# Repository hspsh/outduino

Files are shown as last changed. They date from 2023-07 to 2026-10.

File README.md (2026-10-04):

# Outduino

This is a board we did back in 2023, for our ninja warrior timer.

The core requirements of the projects were - create a device that would:
* drive 2 HDMI outputs (for timer output)
* Register inputs from large switches, on very long cables
* Flash LED outputs.

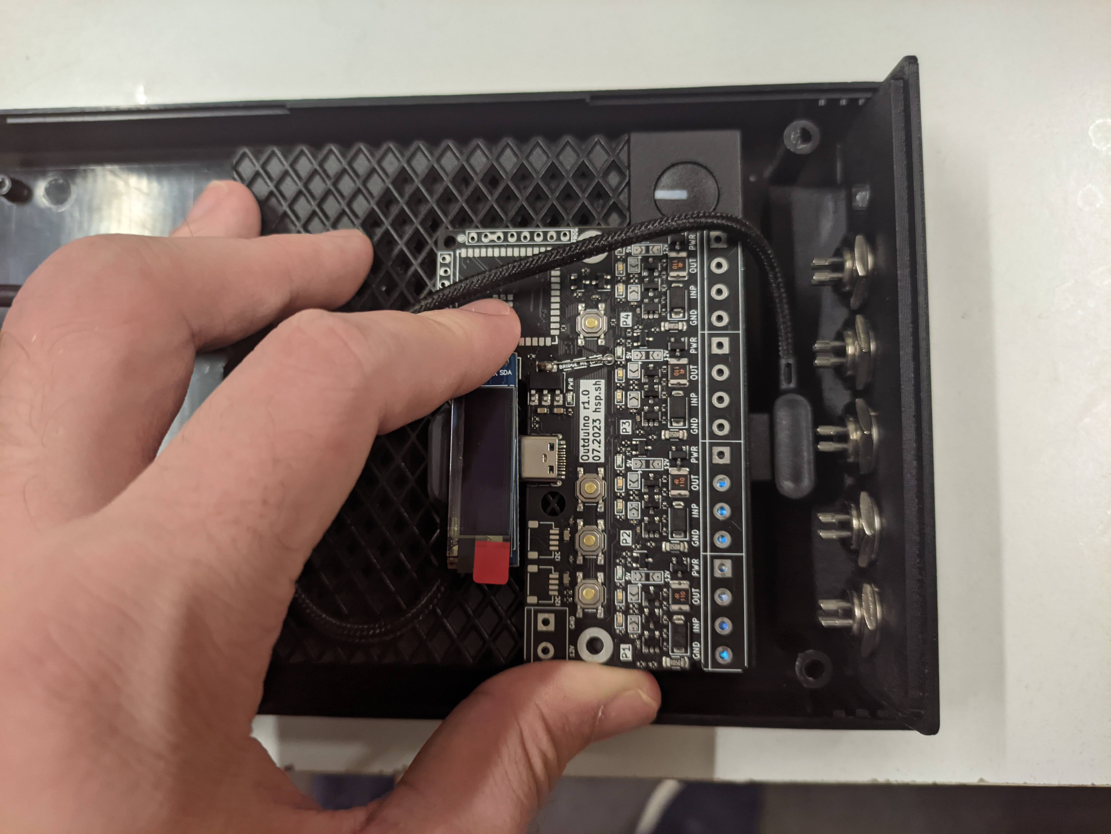
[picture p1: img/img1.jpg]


At first we considered adding some I/O buffer circuitry to raspberry pi, but we decided that a cheaper and more reliable version (if not the more interesting one!) would consist of a Dell Wyse 3040 hidden inside a case, and having a standalone, overengineered, ESP-based IO module drive and read Inputs/Outputs. This is how Outduino was made.

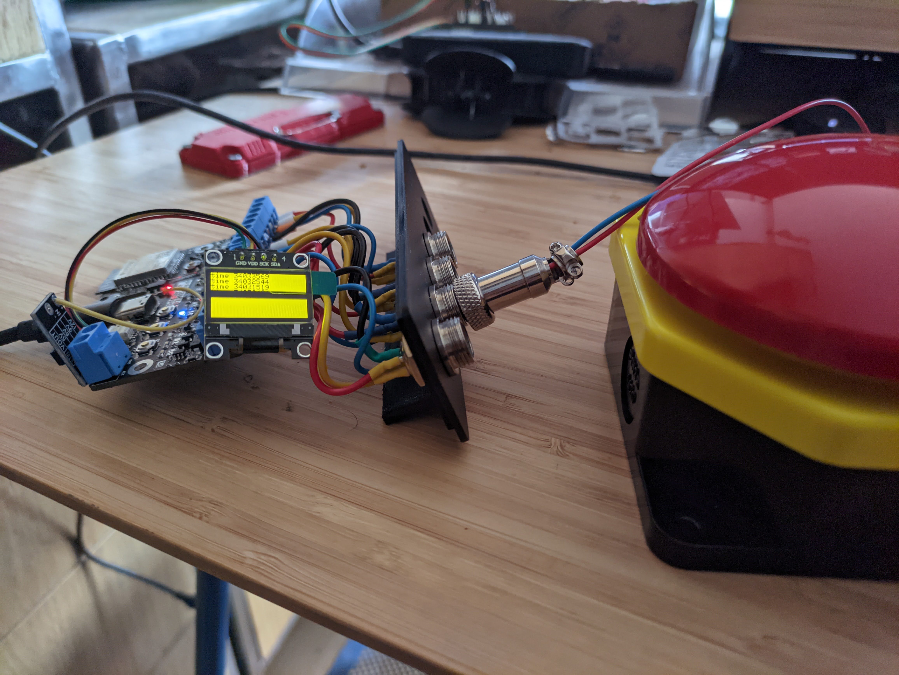
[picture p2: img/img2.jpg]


## I/O block

The device contains 4 overengineered blocks of I/O. These should be able to handle very long cables, as long as the peripherals are not going across different electrical phases. This installation was used outdoor, so this is fine.

As I'm writing this, the year is 2026, I'm 3 years wiser, and I'd probably go full galvanic isolation for both input (optocoupler) and output (something like B0505S isolated converter).



## ESP32

The board connects via USB, and uses very simple API via serial port, to control I/O from software running on host machine.

This part worked well.

In future, the board could've been made to work wirelessly. There's even a footprint for CC1101 sub-ghz wireless IC connection. These functionalities were never added to the firmware.



## Thank yous

Thank you LiquidLemon, not7cd, for inviting me to the project.

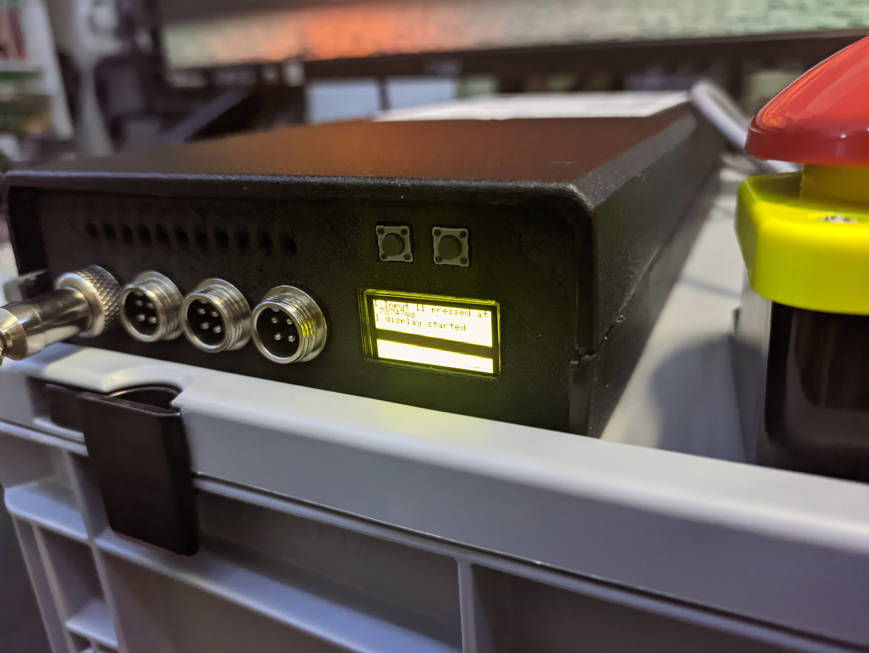
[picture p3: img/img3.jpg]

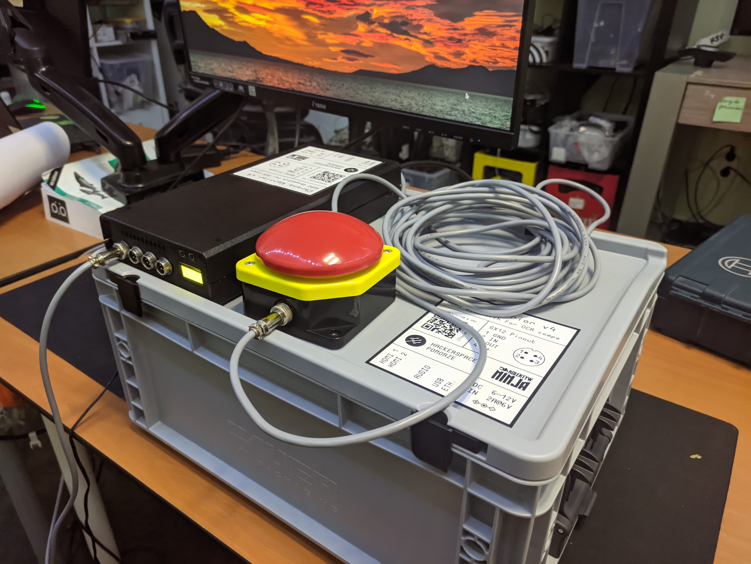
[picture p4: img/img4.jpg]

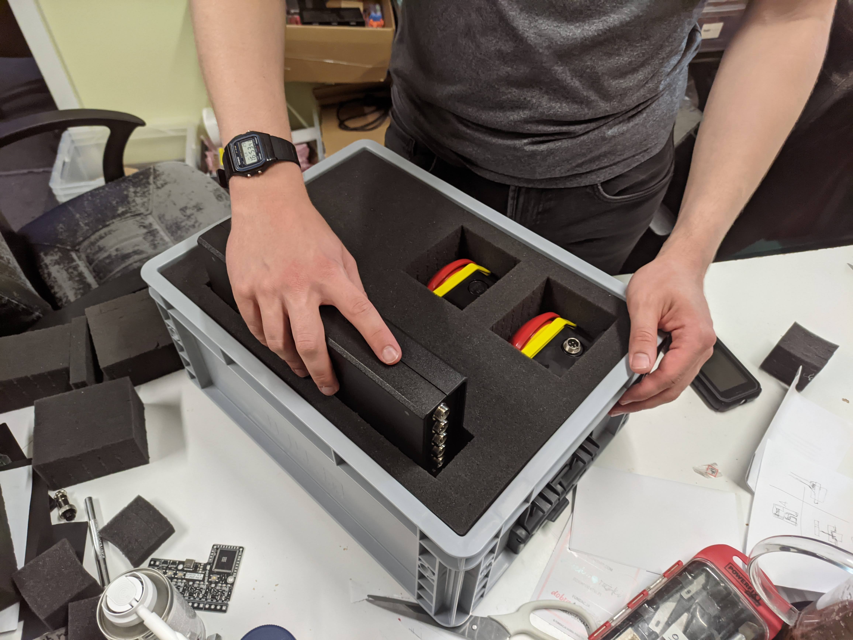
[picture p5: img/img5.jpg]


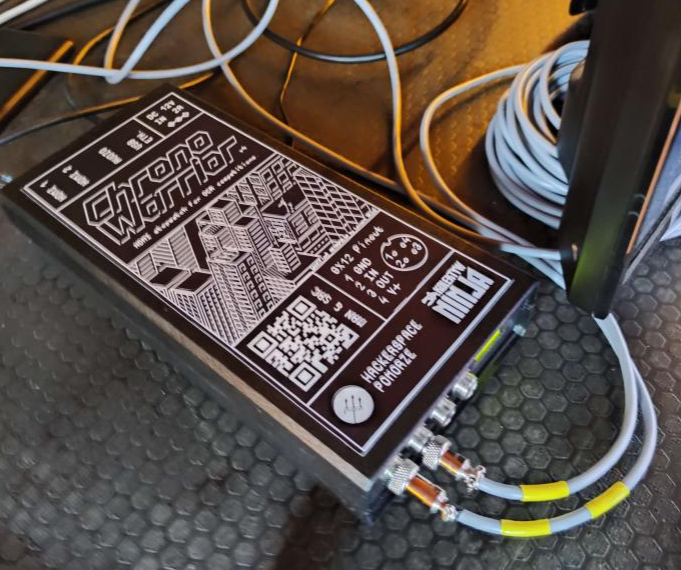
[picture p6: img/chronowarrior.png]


[Project website](https://hsp.sh/chronowarrior)

## License

Copyright 2023 Jakub "cr1tbit" Sadowski.

* **Hardware** (KiCad sources, production files and this documentation) is
  licensed under the [CERN-OHL-P v2](LICENSE) (permissive). You may
  redistribute and modify it and make products using it under the terms of
  that licence.
* **Firmware** in [outduino-fw/](outduino-fw/) is licensed under the
  [MIT License](outduino-fw/LICENSE).

This source is distributed WITHOUT ANY EXPRESS OR IMPLIED WARRANTY, INCLUDING
OF MERCHANTABILITY, SATISFACTORY QUALITY AND FITNESS FOR A PARTICULAR PURPOSE.
Please see the CERN-OHL-P v2 for applicable conditions.

Symbols and footprints from the KiCad and Espressif libraries embedded in the
design files remain under their respective licences.

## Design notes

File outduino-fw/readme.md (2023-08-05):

esptool.py --chip ESP32-S3 merge_bin -o merged-flash.bin --flash_size=keep 0x00000 bootloader.bin 0x8000 partitions.bin 0xe000 ~/.platformio/packages/framework-arduinoespressif32/tools/partitions/boot_app0.bin 0x10000 firmware.bin

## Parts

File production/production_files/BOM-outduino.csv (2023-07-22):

Comment | Designator | Footprint | LCSC
1k | R64,R65,R66,R67 | R_0402_1005Metric | C11702
AO3401A | Q12,Q3,Q6,Q9 | SOT-23 | C15127
100n | C1,C10,C11,C12,C13,C14,C15,C5,C6,C7,C8,C9 | C_0402_1005Metric | C1525
USB_C_Receptacle_USB2.0 | J1 | USB_C_Receptacle_HRO_TYPE-C-31-M-12 | C165948
1812_2A | F1,F2,F3,F4 | Fuse_1812_4532Metric | C20999
LED_RED | D1,D12,D17,D4,D7 | LED_0603_1608Metric | C2286
330/0.1% | R36,R37,R46,R48 | R_0402_1005Metric | C25104
5.1k | R3 | R_0402_1005Metric | C25117
100k | R29,R30,R31 | R_0402_1005Metric | C25741
10k | R1,R10,R11,R12,R13,R14,R19,R21,R22,R23,R24,R25,R26,R27,R28,R33,R39,R40,R41,R42,R43,R45,R49,R51,R52,R53,R54,R55,R57,R58,R60,R61,R63,R68,R69,R7,R70,R71,R72,R73,R74,R75,R8,R9 | R_0402_1005Metric | C25744
3k | R15,R16,R18,R32,R35,R38,R4,R44,R47,R5,R50,R56,R59,R62 | R_0402_1005Metric | C25890
5.1k | R2 | R_0402_1005Metric | C25905
D_TVS | D11,D16,D21,D3 | D_SMA | C3019524
RST | SW1,SW3,SW4,SW5 | SW_SPST_TL3342 | C318884
AZ1117-3.3 | U2 | SOT-223-3_TabPin2 | C6186
LED_BLUE | D14,D19,D6,D9 | LED_0603_1608Metric | C72041
LED_GREEN | D13,D18,D5,D8 | LED_0603_1608Metric | C72043
LMV321 | U4,U5,U6,U7 | SOT-23-5 | C7972
MMBT2222A | Q1,Q10,Q11,Q13,Q14,Q15,Q16,Q17,Q18,Q2,Q4,Q5,Q7,Q8 | SOT-23 | C8512
50mR/1206 | R17,R20,R34,R6 | R_1206_3216Metric_Pad1.30x1.75mm_HandSolder | C912768
10u | C16,C17,C2,C3,C4 | C_0603_1608Metric | C96446

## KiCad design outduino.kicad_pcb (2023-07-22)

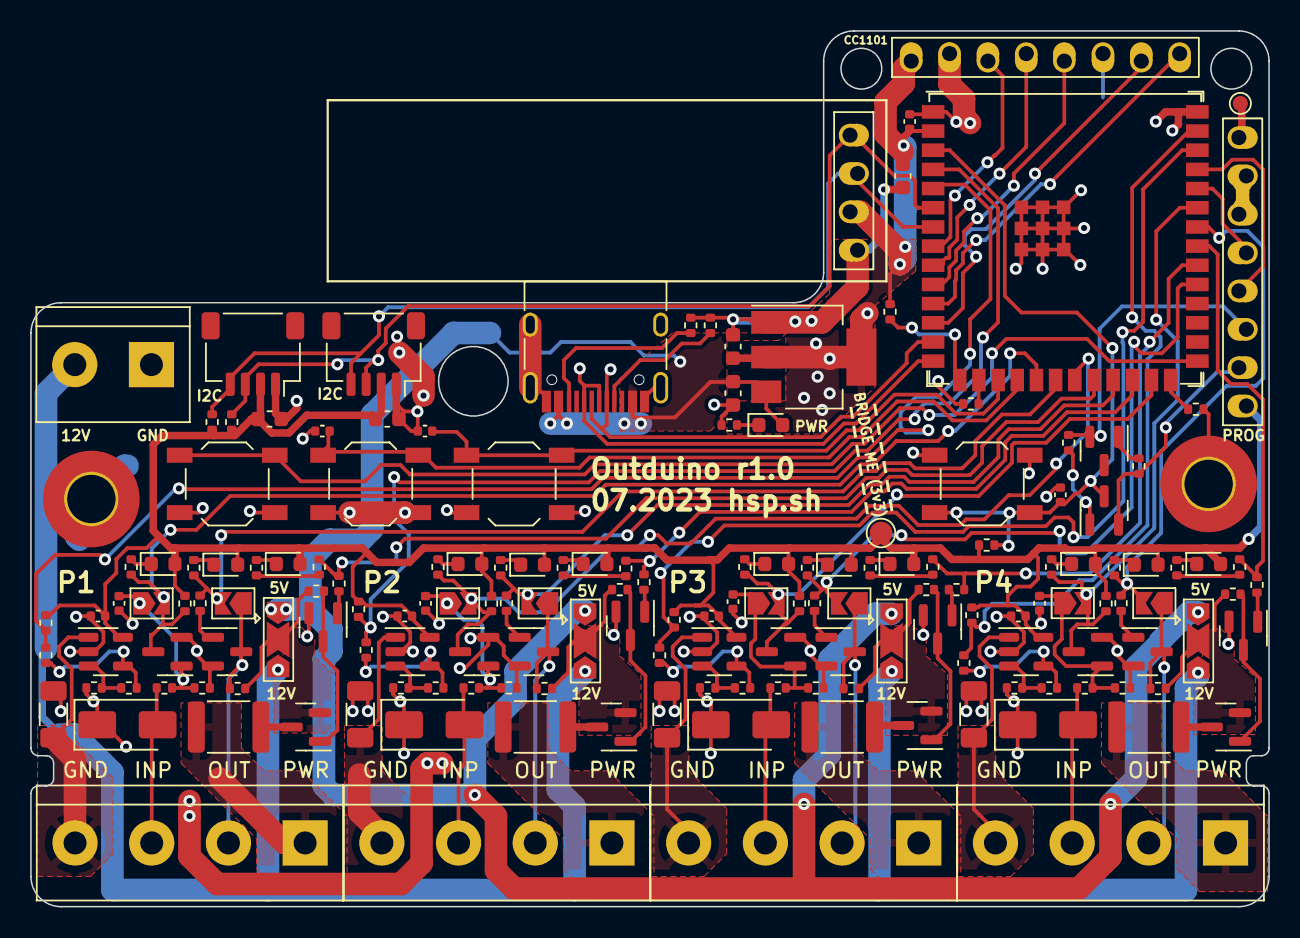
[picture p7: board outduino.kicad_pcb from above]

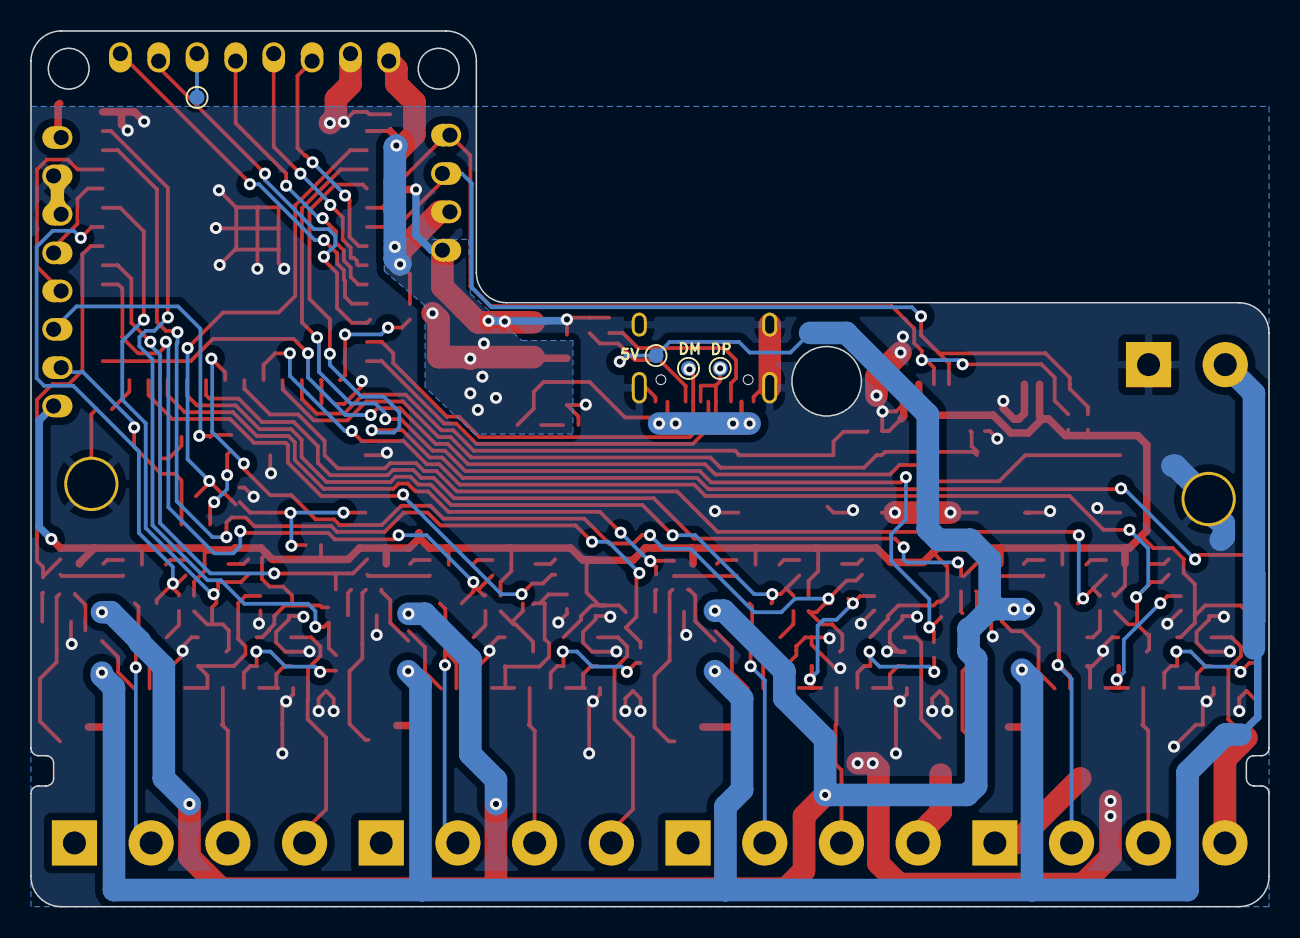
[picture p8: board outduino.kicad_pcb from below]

Board: 2 copper layers, 82.0 x 58.0 mm, 172 parts (4 on the bottom side), 111 nets.

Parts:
C1, C5, C6, C7, C8, C9, C10, C11, C12, C13, C14, C15: 100n; C_0402_1005Metric
C2, C3, C4, C16, C17: 10u; C_0603_1608Metric
D1, D4, D7, D12, D17: LED_RED; LED_0603_1608Metric
D3, D11, D16, D21: D_TVS; D_SMA
D5, D8, D13, D18: LED_GREEN; LED_0603_1608Metric
D6, D9, D14, D19: LED_BLUE; LED_0603_1608Metric
F1, F2, F3, F4: 1812_2A; Fuse_1812_4532Metric
H1, H3: SCR; MountingHole_3.2mm_M3_Pad_TopOnly
J1: USB_C_Receptacle_USB2.0; USB_C_Receptacle_HRO_TYPE-C-31-M-12
J2: Lichtenprog_conn; Lichtenprog
J3: Conn_01x02; TerminalBlock_bornier-2_P5.08mm
J4, J6: QWIIC; JST_SH_SM04B-SRSS-TB_1x04-1MP_P1.00mm_Horizontal
J5, J7, J8, J9: Conn_01x04; TerminalBlock_bornier-4_P5.08mm
J10: CC1101_CONN; 8pin_skewed
JP3, JP4, JP5, JP6: VSEL; SolderJumper-3_P2.0mm_Open_TrianglePad1.0x1.5mm
JP7, JP8, JP9, JP10: OUT_BYP; SolderJumper-2_P1.3mm_Open_TrianglePad1.0x1.5mm
JP11, JP12, JP13, JP14: IN_BYP; SolderJumper-2_P1.3mm_Open_TrianglePad1.0x1.5mm
Q1, Q2: MMBT2222A; SOT-23
Q3, Q6, Q9, Q12: AO3401A; SOT-23
Q4, Q5, Q7, Q8, Q10, Q11, Q13, Q14, Q15, Q16, Q17, Q18: BC847; SOT-23
R1, R7, R8, R9, R10, R11, R12, R13, R14, R19, R21, R22, R23, R24, R25, R26, R27, R28, R33, R39, R40, R41, R42, R43, R45, R49, R51, R52, R53, R54, R55, R57, R58, R60, R61, R63, R68, R69, R70, R71, R72, R73, R74, R75: 10k; R_0402_1005Metric
R2, R3: 5.1k; R_0402_1005Metric
R4, R5, R15, R16, R18, R32, R35, R38, R44, R47, R50, R56, R59, R62: 3k; R_0402_1005Metric
R6, R17, R20, R34: 50mR/1206; R_1206_3216Metric_Pad1.30x1.75mm_HandSolder
R29, R30, R31: 100k; R_0402_1005Metric
R36, R37, R46, R48: 330/0.1%; R_0402_1005Metric
R64, R65, R66, R67: 1k; R_0402_1005Metric
SW1: RST; SW_SPST_TL3342
SW3: B1/BOOT; SW_SPST_TL3342
SW4, SW5: B2; SW_SPST_TL3342
TP1, TP2, TP3, TP4, TP5: IOPAD; TestPoint_Pad_D1.0mm
TP6: IOPAD; TestPoint_Pad_D1.5mm
U1: OLED_4Pin
U2: AZ1117-3.3; SOT-223-3_TabPin2
U3: ESP32-S3-WROOM-2; ESP32-S3-WROOM-1U
U4, U5, U6, U7: LMV321; SOT-23-5

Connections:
+3.3V: C1.1, C2.1, C4.1, C10.1, C13.1, C14.1, C15.1, C16.1, C17.1, D4.2 (A), D5.2 (A), D6.2 (A), D7.2 (A), D8.2 (A), D9.2 (A), D12.2 (A), D13.2 (A), D14.2 (A), D17.2 (A), D18.2 (A), D19.2 (A), J2.1 (VDD), J4.2, J6.2, J10.1, R4.2, R5.2, R16.2, R25.2, R30.2, R35.2, R47.2, R59.2, R68.1, R69.1, R70.1, R71.1, TP6.1, U1.2 (VCC), U2.2 (VO), U3.2 (3V3), U4.5 (V+), U5.5 (V+), U6.5 (V+), U7.5 (V+)
+12V: J3.2, JP3.3 (B), JP4.3 (B), JP5.3 (B), JP6.3 (B)
/CC1101_CSn: J10.8, U3.11 (GPIO18/U1RXD/ADC2_CH7/CLK_OUT3)
/CC1101_GDO0: J10.7, U3.12 (GPIO8/TOUCH8/ADC1_CH7/SUBSPICS1)
/CC1101_GDO2: J10.6, TP5.1
/CC1101_SCLK: J10.4, U3.9 (GPIO16/U0CTS/ADC2_CH5/XTAL_32K_NH5)
/CC1101_SI: J10.3, U3.8 (GPIO15/U0RTS/ADC2_CH4/XTAL_32K_P)
/CC1101_SO: J10.5, U3.10 (GPIO17/U1TXD/ADC2_CH6)
/CURR1: R64.1, R68.2, U3.5 (GPIO5/TOUCH5/ADC1_CH4)
/CURR2: R65.1, R69.2, U3.4 (GPIO4/TOUCH4/ADC1_CH3)
/CURR3: R66.1, R70.2, U3.38 (GPIO2/TOUCH2/ADC1_CH1)
/CURR4: R67.1, R71.2, U3.39 (GPIO1/TOUCH1/ADC1_CH0)
/DTR: J2.3 (DTR), Q2.2 (E), R7.1
/ESP_B2: C11.1, SW4.2, U3.17 (GPIO9/TOUCH9/ADC1_CH8/FSPIHD/SUBSPIHD)
/ESP_B3: C12.1, SW5.2, U3.18 (GPIO10/TOUCH10/ADC1_CH9/FSPICS0/FSPIIO4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)
/ESP_BOOT_B1: SW3.2, U3.27 (GPIO0/BOOT)
/ESP_EN: C8.1, Q1.3 (C), R25.1, SW1.2, U3.3 (EN)
/IN1: JP11.2 (B), Q5.3 (C), R16.1, R23.1, U3.19 (GPIO11/TOUCH11/ADC2_CH0/FSPID/FSPIIO5/S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)
/IN2: JP12.2 (B), Q8.3 (C), R27.1, R35.1, U3.21 (GPIO13/TOUCH13/ADC2_CH2/FSPIQ/FSPIIO7/S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)
/IN3: JP13.2 (B), Q11.3 (C), R42.1, R47.1, U3.25 (GPIO48/SPICLK_N/SUBSPICLK_N_DIFF)
/IN4: JP14.2 (B), Q14.3 (C), R54.1, R59.1, U3.35 (MTMS/GPIO42)
/IO_block1/GND_BANK: J5.4, R6.1, U4.1 (+)
/IO_block1/INP_BANK: D3.2 (A2), J5.3, R18.1
/IO_block1/OUT_BANK: J5.2, JP7.1 (A), Q4.3 (C), R15.1
/IO_block1/PWR: JP3.2 (C), Q3.2 (S), R14.2, R15.2
/IO_block1/PWR_BANK: F1.2, J5.1
/IO_block2/GND_BANK: J7.4, R17.1, U5.1 (+)
/IO_block2/INP_BANK: D11.2 (A2), J7.3, R38.1
/IO_block2/OUT_BANK: J7.2, JP8.1 (A), Q7.3 (C), R32.1
/IO_block2/PWR: JP4.2 (C), Q6.2 (S), R32.2, R33.2
/IO_block2/PWR_BANK: F2.2, J7.1
/IO_block3/GND_BANK: J8.4, R20.1, U6.1 (+)
/IO_block3/INP_BANK: D16.2 (A2), J8.3, R50.1
/IO_block3/OUT_BANK: J8.2, JP9.1 (A), Q10.3 (C), R44.1
/IO_block3/PWR: JP5.2 (C), Q9.2 (S), R44.2, R45.2
/IO_block3/PWR_BANK: F3.2, J8.1
/IO_block4/GND_BANK: J9.4, R34.1, U7.1 (+)
/IO_block4/INP_BANK: D21.2 (A2), J9.3, R62.1
/IO_block4/OUT_BANK: J9.2, JP10.1 (A), Q13.3 (C), R56.1
/IO_block4/PWR: JP6.2 (C), Q12.2 (S), R56.2, R57.2
/IO_block4/PWR_BANK: F4.2, J9.1
/OUT1: JP7.2 (B), R9.2, R22.1, U3.20 (GPIO12/TOUCH12/ADC2_CH1/FSPICLK/FSPIIO6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)
/OUT2: JP8.2 (B), R10.2, R26.1, U3.23 (GPIO21)
/OUT3: JP9.2 (B), R11.2, R41.1, U3.31 (GPIO38/FSPIWP/SUBSPIWP)
/OUT4: JP10.2 (B), R12.2, R53.1, U3.34 (MTDI/GPIO41/CLK_OUT1)
/PWR1: R24.1, R72.2, U3.22 (GPIO14/TOUCH14/ADC2_CH3/FSPIWP/FSPIDQS/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)
/PWR2: R28.1, R73.2, U3.24 (GPIO47/SPICLK_P/SUBSPICLK_P_DIFF)
/PWR3: R43.1, R74.2, U3.32 (MTCK/GPIO39/CLK_OUT3/SUBSPICS1)
/PWR4: R55.1, R75.2, U3.33 (MTDO/GPIO40/CLK_OUT2)
/RTS: J2.2 (RTS), Q1.2 (E), R8.1
/SCL: J4.4, J6.4, R4.1, U1.3 (SCL), U3.7 (GPIO7/TOUCH7/ADC1_CH6)
/SDA: J4.3, J6.3, R5.1, U1.4 (SDA), U3.6 (GPIO6/TOUCH6/ADC1_CH5)
/TARG_RX: J2.5 (PROG_TX), U3.36 (U0RXD/GPIO44/CLK_OUT2)
/TARG_TX: J2.4 (PROG_RX), U3.37 (U0TXD/GPIO43/CLK_OUT1)
/USBDM: J1.A7 (D-), J1.B7 (D-), TP3.1, U3.13 (GPIO19/U1RTS/ADC2_CH8/CLK_OUT2/USB_D-)
/USBDP: J1.A6 (D+), J1.B6 (D+), TP2.1, U3.14 (GPIO20/U1CTS/ADC2_CH9/CLK_OUT1/USB_D+)
GND: C1.2, C2.2, C3.2, C4.2, C5.2, C6.2, C7.2, C8.2, C9.2, C10.2, C11.2, C12.2, C13.2, C14.2, C15.2, C16.2, C17.2, D3.1 (A1), D11.1 (A1), D16.1 (A1), D21.1 (A1), H1.1, H3.1, J1.A1 (GND), J1.A12 (GND), J1.B1 (GND), J1.B12 (GND), J1.S1 (SHIELD), J2.6 (GND), J2.7 (GND), J3.1, J4.1, J6.1, J10.2, Q4.2 (E), Q5.2 (E), Q7.2 (E), Q8.2 (E), Q10.2 (E), Q11.2 (E), Q13.2 (E), Q14.2 (E), Q15.2 (E), Q16.2 (E), Q17.2 (E), Q18.2 (E), R2.2, R3.2, R6.2, R13.1, R17.2, R19.1, R20.2, R29.1, R31.1, R34.2, R36.2, R37.2, R39.1, R46.2, R48.2, R51.1, R63.1, SW1.1, SW3.1, SW4.1, SW5.1, U1.1 (GND), U2.1 (GND), U3.1 (GND), U3.40 (GND), U3.41 (GND), U4.2 (V-), U5.2 (V-), U6.2 (V-), U7.2 (V-)
unnamed: D1.1 (K), R13.2
unnamed: D4.1 (K), R21.2
unnamed: D5.1 (K), R22.2
unnamed: D6.1 (K), R23.2
unnamed: D7.1 (K), R1.2
unnamed: D8.1 (K), R26.2
unnamed: D9.1 (K), R27.2
unnamed: D12.1 (K), R40.2
unnamed: D13.1 (K), R41.2
unnamed: D14.1 (K), R42.2
unnamed: D17.1 (K), R52.2
unnamed: D18.1 (K), R53.2
unnamed: D19.1 (K), R54.2
unnamed: J1.A5 (CC1), R2.1
unnamed: J1.B5 (CC2), R3.1
unnamed: J2.8 (5V), TP4.1
unnamed: C5.1, JP11.1 (A), Q5.1 (B), R18.2, R19.2
unnamed: C6.1, JP12.1 (A), Q8.1 (B), R38.2, R39.2
unnamed: C7.1, JP13.1 (A), Q11.1 (B), R50.2, R51.2
unnamed: C9.1, JP14.1 (A), Q14.1 (B), R62.2, R63.2
unnamed: Q1.1 (B), R7.2
unnamed: Q2.1 (B), R8.2
unnamed: F1.1, Q3.3 (D)
unnamed: Q4.1 (B), R9.1
unnamed: F2.1, Q6.3 (D)
unnamed: Q7.1 (B), R10.1
unnamed: F3.1, Q9.3 (D)
unnamed: Q10.1 (B), R11.1
unnamed: F4.1, Q12.3 (D)
unnamed: Q12.1 (G), Q18.3 (C), R57.1
unnamed: Q13.1 (B), R12.1
unnamed: Q15.1 (B), R72.1
unnamed: Q3.1 (G), Q15.3 (C), R14.1
unnamed: Q16.1 (B), R73.1
unnamed: Q6.1 (G), Q16.3 (C), R33.1
unnamed: Q17.1 (B), R74.1
unnamed: Q9.1 (G), Q17.3 (C), R45.1
unnamed: Q18.1 (B), R75.1
unnamed: R1.1, R28.2
unnamed: R21.1, R24.2
unnamed: R40.1, R43.2
unnamed: R49.1, R64.2, U4.4
unnamed: R52.1, R55.2
unnamed: R58.1, R65.2, U5.4
unnamed: R60.1, R66.2, U6.4
unnamed: R61.1, R67.2, U7.4
unnamed: R30.1, U3.15 (GPIO3/TOUCH3/ADC1_CH2)
unnamed: R31.2, U3.26 (GPIO45)
unnamed: R29.2, U3.16 (GPIO46)
unnamed: R36.1, R49.2, U4.3 (-)
unnamed: R37.1, R58.2, U5.3 (-)
unnamed: R46.1, R60.2, U6.3 (-)
unnamed: R48.1, R61.2, U7.3 (-)
VBUS: C3.1, D1.2 (A), J1.A4 (VBUS), J1.A9 (VBUS), J1.B4 (VBUS), J1.B9 (VBUS), JP3.1 (A), JP4.1 (A), JP5.1 (A), JP6.1 (A), TP1.1, U2.3 (VI)

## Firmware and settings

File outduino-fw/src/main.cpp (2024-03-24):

#include <Arduino.h>
#undef B1 //try to comment out this line to see something funny

#include <Wire.h>
#include <Adafruit_GFX.h>
#include <Adafruit_SSD1306.h>
#include <Button2.h>

#include <fmt/ranges.h>
#include <alfalog.h>
#include "advancedOledLogger.h"

#include <commonFwUtils.h>

#include <main.h>
#include <pinDefs.h>

#define FW_REV "0.1.0"

QueueHandle_t eventMsgQueue = NULL;
TimerHandle_t debounceTimer = NULL;

void SerialReceiveTask( void * parameter );
void EvtDigestTask( void * parameter );

TwoWire i2c = TwoWire(0);

std::vector<OutduinoBank> banks = {{
  OutduinoBank(PWR1, IN1, OUT1, CURR1, ISR_FOR_PIN_BANK(IN1, 1)),
  OutduinoBank(PWR2, IN2, OUT2, CURR2, ISR_FOR_PIN_BANK(IN2, 2)),
  OutduinoBank(PWR3, IN3, OUT3, CURR3, ISR_FOR_PIN_BANK(IN3, 3)),
  OutduinoBank(PWR4, IN4, OUT4, CURR4, ISR_FOR_PIN_BANK(IN4, 4))
}};

void uartPrintAlogHandle(const char* str){
  Serial.println(str);
}

void sendIoEvt(const cringeEvtContainer_t *p_evt){
  if(eventMsgQueue != NULL){
    xQueueSendFromISR(eventMsgQueue, p_evt, 0);
  }
}

void outduinoPinIsrHandle(const int pin, const int bank){
  cringeEvtContainer_t evt;
  evt.type = CRINGE_EVT_TYPE_INPUT;
  evt.inputEvt = {
    .input_num = bank,
    .is_high = digitalRead(pin) != LOW,
    .timestamp = millis()
  };
  sendIoEvt(&evt);
}

AdvancedOledLogger aOledLogger = AdvancedOledLogger(i2c, LOG_INFO, OLED_128x64);
SerialLogger serialLogger = SerialLogger(uartPrintAlogHandle, LOG_DEBUG);
Button2 userButton = Button2();

void setup() {  
  Serial.begin(115200);
  Serial.setTxTimeoutMs(0); // prevent logger slowdown when no usb connected
  Serial.println("begin...");
  // delay(3000);
  // bootloopOnButtonPress(PIN_B2);
  i2c.begin(SDA, SCL, 100000);

  AlfaLogger.addBackend(&aOledLogger);
  AlfaLogger.addBackend(&serialLogger);
  AlfaLogger.begin();
  ALOGI("display started");
  aOledLogger.setTopBarText(BAR_CUSTOM, "NinjaTimer r. " FW_REV);

  // ALOGI(
  //   "i2c device found at 0x{:02x}", 
  //   fmt::join(scan_i2c(i2c), ", 0x"));
  // initPins(banks);

  for (auto &b: banks){
    b.setPower(PWR_ON);
  }

  userButton.begin(PIN_B2, INPUT_PULLUP, false);
  userButton.setTapHandler([](Button2 & b){
    cringeEvtContainer_t evt;
    evt.type = CRINGE_EVT_TYPE_INPUT;
    evt.inputEvt = {
      .input_num = PIN_B2,
      .is_high = digitalRead(PIN_B2) != LOW,
      .timestamp = millis()
    };
    sendIoEvt(&evt);
  });

  eventMsgQueue = xQueueCreate( 10, sizeof( cringeEvtContainer_t ) );  
  xTaskCreate( EvtDigestTask, "EvtDigestTask",
    3000, NULL, 2, NULL );

  xTaskCreate( SerialReceiveTask, "serial task",
    3000, NULL, 2, NULL );
}

#define OUTDUINO_ECHO_SERIAL
void parseSerialEvent(const std::vector<char> buf){
  if (buf.size() < 3){
    #ifdef OUTDUINO_ECHO_SERIAL
      Serial.println();
    #endif
  } else {
    if (buf.front() == '<' && buf.back() == '>'){
      std::string cmd(buf.begin()+1, buf.end()-1);

      cringeEvtContainer_t evt;
      evt.type = CRINGE_EVT_TYPE_SERIAL;
      strncpy(evt.serialEvt.cmd, cmd.c_str(), sizeof(evt.serialEvt.cmd));

      if(eventMsgQueue != NULL){
        xQueueSend(eventMsgQueue, &evt, 0);
      }
    }
  }
}

void SerialReceiveTask( void * parameter ) {
  std::vector<char> buf;
  while(1){
    while (Serial.available()) {
      char c = Serial.read();
      
      switch (c){
        case '\r': 
        #ifdef OUTDUINO_ECHO_SERIAL
          Serial.print('\r');  //echo if character accepted
        #endif
        break;
        case '\n': {
          parseSerialEvent(buf);
          buf.clear();
          break;
        }
        default: {
          if(buf.size() <= 32){
            buf.push_back(c);
            #ifdef OUTDUINO_ECHO_SERIAL
              Serial.print(c);  //echo if character accepted
            #endif
          }
        }
      }
    }
    vTaskDelay(100/portTICK_PERIOD_MS);
  }
}

void serialAction(cringeEvtContainer_t& evt){
  //frick off chatgpt wrote this
  if (strncmp(evt.serialEvt.cmd, "set", 3) == 0){
    int bank = atoi(evt.serialEvt.cmd+3);
    if (bank > 0 && bank <= banks.size()){
      banks[bank-1].setOutput(OUT_HI);
    }
  } else if (strncmp(evt.serialEvt.cmd, "clr", 3) == 0){
    int bank = atoi(evt.serialEvt.cmd+3);
    if (bank > 0 && bank <= banks.size()){
      banks[bank-1].setOutput(OUT_LO);
    }
  } else if (strncmp(evt.serialEvt.cmd, "on", 2) == 0){
    int bank = atoi(evt.serialEvt.cmd+2);
    if (bank > 0 && bank <= banks.size()){
      banks[bank-1].setPower(PWR_ON);
    }
  } else if (strncmp(evt.serialEvt.cmd, "off", 3) == 0){
    int bank = atoi(evt.serialEvt.cmd+3);
    if (bank > 0 && bank <= banks.size()){
      banks[bank-1].setPower(PWR_OFF);
    }
  } else if (strncmp(evt.serialEvt.cmd, "status", 6) == 0){
    for (auto &b: banks){
      ALOGR(b.to_string().c_str());
    }
  } else if (strncmp(evt.serialEvt.cmd, "help", 4) == 0){
    ALOGR("set1 - set bank 1");
    ALOGR("clr1 - clr bank 1");
    ALOGR("toggle1 - toggle bank 1");
    ALOGR("status - show status of all banks");
  } else if (strncmp(evt.serialEvt.cmd, "view", 4) == 0){
    aOledLogger.setTopBarText(BAR_CUSTOM, std::string(evt.serialEvt.cmd+4));
  } else if (strncmp(evt.serialEvt.cmd, "log", 3) == 0){
    ALOGI("{}", evt.serialEvt.cmd+3);
  }
}

void EvtDigestTask( void * parameter ) {
  cringeEvtContainer_t evt;
  while(1){
    if(xQueueReceive(eventMsgQueue, &evt, 1000/portTICK_PERIOD_MS) == pdTRUE){
      
      if(evt.type == CRINGE_EVT_TYPE_INPUT){
        Serial.println(evt.serialize().c_str());
      } else if (evt.type == CRINGE_EVT_TYPE_SERIAL){
        ALOGD(evt.to_string().c_str());
        serialAction(evt);
      }     

    } else {
      // ALOGD("time {}", millis());
    }
  }
}

void loop() {
    handle_io_pattern(OUT3,PATTERN_HBEAT);
    userButton.loop();
    vTaskDelay(50/portTICK_PERIOD_MS);

    static int counter = 0;
    if (counter++ % 8 == 0){
      aOledLogger.redraw();
    }
}

void initPins(std::vector<OutduinoBank> banks){
  OutduinoBank::setEvtHandle(outduinoPinIsrHandle);

  for(auto &b: banks){
    b.init();
  }

  pinMode(BOOT_B1, INPUT);
  pinMode(PIN_B3, INPUT_PULLUP);
}

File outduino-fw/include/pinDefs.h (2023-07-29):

#pragma once

#define ESP_TX 37
#define ESP_RX 36

#define OUT1 12
#define OUT2 21
#define OUT3 38
#define OUT4 41

#define IN1 11
#define IN2 13
#define IN3 48
#define IN4 42

#define PWR1 14
#define PWR2 47
#define PWR3 39
#define PWR4 41

#define CURR1 5
#define CURR2 4
#define CURR3 2
#define CURR4 1

#define BOOT_B1 0
#define PIN_B2 9
#define PIN_B3 10


#define SDA 6
#define SCL 7

#define CC1101_SCLK 16
#define CC1101_SI 15
#define CC1101_SO 17
#define CC1101_CS 18
#define CC1101_GDO0 8

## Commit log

2023-06-11 add kicad
    [IO_block.kicad_sch, outduino.kicad_pcb, outduino.kicad_sch]
2023-07-16 before scripts
    [IO_block.kicad_sch, outduino.kicad_pcb, outduino.kicad_sch]
2023-08-07 move stuff to libraries on github, change crappy pin ISR management to less crappy, forgive C++
2023-08-28 no compile but will fix
    [main.cpp, outduino.h]
2026-10-03 add license, update readme
    [IO_block.kicad_sch, outduino.kicad_sch]
